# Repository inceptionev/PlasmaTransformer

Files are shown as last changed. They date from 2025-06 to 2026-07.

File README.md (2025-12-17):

# Plasma Transformer

<p align="center">
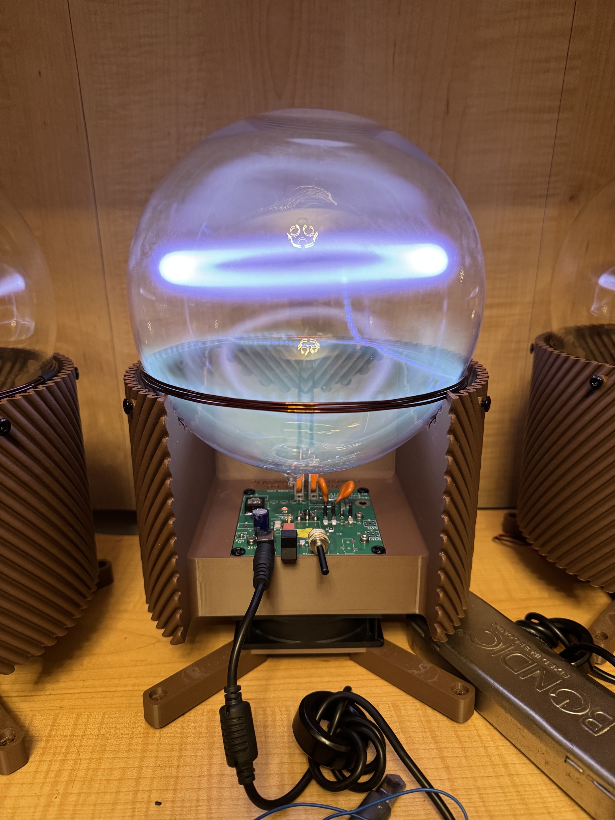
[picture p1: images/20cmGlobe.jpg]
  
</p>

## An open-source plasma toroid project by inceptionev (Dr. Bunga)

This project mainly focuses on creating a driver and 3D-printed support structure that allows for safe continuous operation of a plasma toroid.  The objectives are stable operation of a levitating halo of plasma at maximum height above the coil and protection against touching energized components, while providing airflow to keep both the electronics and the globe cool.  The globes are filled with a low-pressure of xenon gas.

### Key Features of this project:
- Plasma Driver PCB with experimentation-friendly features:
  - Wide input power range from 12-60V for easy power control.  Onboard 12V supply for stable fan and gate drive.
  - High-voltage auto-igniter strikes the plasma whenever plasma is not present, but also does not load the driver when plasma is live.  This helps prevent damage from runaway unloaded oscillation.  Designed in collaboration with @ltwin0.
  - Oscillation detector illuminates to show when the driver is in oscillation, whether or not plasma is present.  Based on a design from Sky-guided.
  - Socketed coil and tank capacitor connectors for easy tuning.
  - Dedicated on-board oscilloscope probes on the MOSFET gate and drain nets for Class-E tuning.  Connect an SMA cable directly from the board to a terminator and the oscilloscope.
  - Selectable Gate-Source cap via jumper headers to tune AC gate drive strenth.
  - Separate power switch and DC Gate Bias control.  Turn it off and on without changing the DC gate bias level.
- 3D printed cooling shroud:
  - Provides directed airflow for cooling both the electronics and the globe for continuous use.
  - Supports the fan, board, coil, and globe with ideal spacing for achieving a levitating plasma halo.
  - Provides attachments for rubber bands to hold the globe in place for environments where the device may be in motion, or to attach a shade to make the plasma more visible in outdoor installations.
  - Includes a cover and coil ring that keeps curious fingers away from the hazardous high-voltage parts. (But caution is always advised around high voltage and RF)
- 3D-printed assembly aids:
  - Coil forms for ease of making the plasma coil.

Special thanks to:  
Sky-guided, whose inductive oscillation indicator design is used in this project.  
@ltwin8, whose RF node parasitic auto-igniter design is used in this project and was detailed in https://github.com/inceptionev/PlasmaTransformer/issues/1  

Native design files and manufacturing files in gerber and stl format are provided for the 20cm and 13cm globe sizes.

<p align="center">
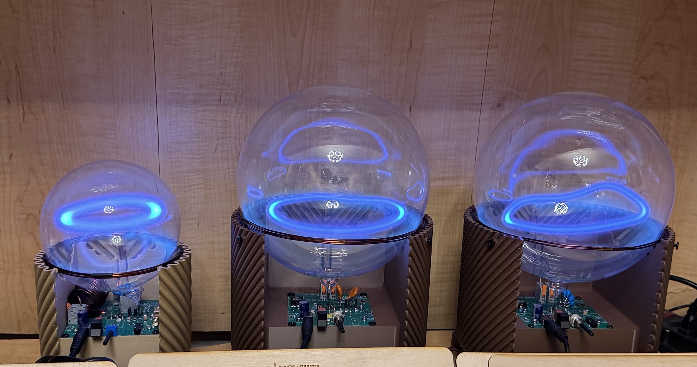
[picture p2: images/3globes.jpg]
  
</p>

KiCAD PCB files are found in the /Plasma Transformer PCB folder.  If you want to edit the design, the files are in the folder.  If you just want to make the boards, you need:
- Plasma Transformer PCB/manufacturing/[the zip file with the latest rev]
- Plasma Transformer PCB/bom/[the bom file matching that rev]

Rev 5 PCB specific note:
The holes for the capacitor sockets are too large, so instead of being press-fit, they will need to be soldered in.  I recommend using a piece of paper tape to hold them in place on the top side, then soldering them on the bottom side.  Or you can skip the sockets and solder in the capacitors directly.

3d print design files and a dxf for the heatsink hole pattern are found in the 3D Print and CNC folder.  The heatsink holes are all M3 drill/tap.

If you are doing turnkey PCBA assembly, you probably want to DNP the fan (M1), heatsink (HS1), MOSFET (Q1), and tank capacitors (C1, C16-20) from the BOM in the Turnkey Assembly ZIP package, as you will assemble these later.

<p align="center">
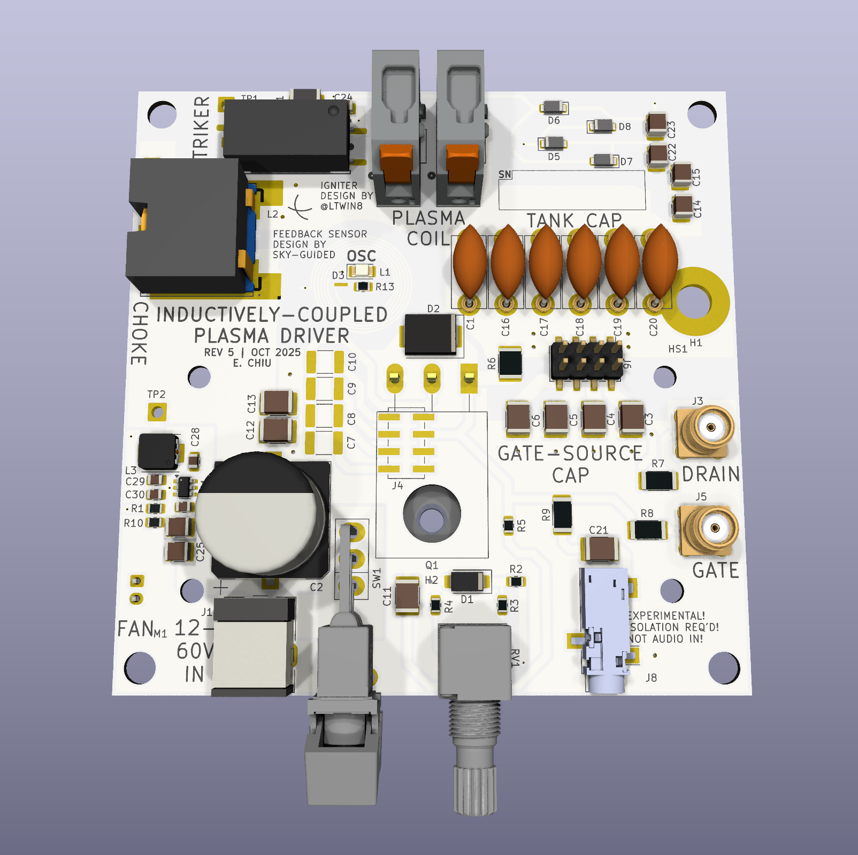
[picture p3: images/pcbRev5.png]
  
</p>

If you just want to print the files, look here:
- /3D Print and CNC/20cm Globe STL 3D Print Set
- /3D Print and CNC/13cm Globe STL 3D Print Set

## Additional Materials Needed:
- 12 AWG magnet wire (2mm dia)
- 12mm or 1/2" polyimide (kapton) tape
- 4x M4*30mm self tapping screws
- 4x M4*8mm self tapping screws
- 4x M3 6x6mm Male/Female threaded standoff
- 4x M3 6mm screws to mount PCB to heatsink
- M3 washers and lockwashers
- JST XHP-2 connector and contacts for fan
- The appropriate capacitor values from the list below
- Thermal pad for TO-247 MOSFET (example: SPK4-0.006-00-104)
- M3*20mm screw, washer, and lockwasher for mounting MOSFET
- 4mm OD x 2.5mm ID PTFE tube (commonly sold as Bowden tube for 1.75mm filament 3D printers)

## Assembly instructions:
- I recommend 3D-printing the coil forms and the spacer ring first, then the cooling shroud, cover, and foot.  You may also want to print a smaller coil form for pre-winding in the first batch, see coil instructions below.
- The main cooling shroud may take 20+ hrs to print, so you can build the heatsink, coil and PCB while it is printing.
- Prepare the heatsink
  - Drill and tap the holes in the heatsink.  They are all M3.  A DXF is provided if you wnat to use a CNC.
  - Mount the MOSFET into the heatsink with thermal pad LOOSELY (do not tighten yet)
  - Bend the MOSFET pins up 90 degrees
  - Install the standoffs into the heatsink
- Assemble the PCB per the BOM EXCEPT for the MOSFET.  That component will be soldered last.
- Mount the PCB to the heatsink with 4x M3x6mm screws, washers, and lockwashers, threading the MOSFET pins through the holes in the board.  Make sure the MOSFET is loose so it can move into alighment with the board.
- Tighten the screws mounting the PCB to the heatsink first.
- Then tighten the mounting screw of the MOSFET to the heatsink.
- Solder the MOSFET in.
- Add connector to the fan.  Pin 1 is positive.
- Make the coil
  - Print out the coil form in the folder for the globe size you are using.
  - Push a length of 12AWG magnet wire in a length of insulating PTFE tube.  It helps if the tube and the wire are both straight.  Taping them to the edge of a table will accomplish this.
    - For the 13cm globe, push 171.6cm of wire into 151.6cm of PTFE tube.  Leave 10cm of wire sticking out at both ends.
	- For the 20cm globe, push 203cm of wire into 175cm of of PTFE tube.  Leave 14cm of wire sticking out at both ends.
  - First wrap the wire and insulator around an object slightly smaller than the coil form.  This will make wrapping on the coil form easier.  You can use the 13cm coil form as the pre-wind form for the 20cm coil. An stl file for an 80mm coil form is also provided to act as the pre-wind for the 13cm coil.
  - Wrap the slightly-smaller coil of wire and insulator onto the coil form.  Start at the lip, and work up from there in a clockwise direction with the lip facing away from you.  This ensures that the bottom coil connects to the RF Node (the right block on the PCB).  This is the higher voltage terminal, and having it on the bottom coil helps with levitation of the plasma.
    - 13cm Globe: you should get 4 coils, minus the 9mm gap where the ends meet.
	- 20cm Globe: you should get 3 coils, minus the 9mm gap where the ends meet.
  - Use the slots in the coil form to tape up the coil so it holds its shape.  Polyimide (Kapton) tape is recommended.
  - Remove the coil from the form and wrap the coil again where the tail meets the coil
  - Open the coil terminal latches on the PCB and fit the coil into the assembly with the PCB, making bends to allow for the envelope of the globe.  Make an 'S' curve at the bottom of the coil wires where they exit the PCB blocks, to allow for adjusting the height.
  - Trim the coil tails if necessary.
  - Burn about 12mm of insulation off the end of the coil tails and clean it up with sandpaper until you can see the shiny copper underneath.  A lighter works well for this.
  - Install the coil spacer ring into the top of the coil, opposite of the direction where the wire tails go.
- Mount the foot and the fan to the bottom with the M4*30mm screws, threading the fan wires through the notch in the bottom.  
- Connect the fan to the PCB.  On the 20mm cooling shroud, a slot is provided in the wall next to the PCB to hold the fan connector temporarily for easy connecting and disconnecting.
- Mount the PCB to the cooling shroud with the M4*8mm screws
- Latch the coil into the PCB.
- Screw in 5x M4x8mm screws into the bosses around the circumference of the cooling shroud. This can be used for shrouds or rubber bands to secure the globe.
- Optionally install the cover into the cooling shroud.

## Known successful values from experimentation:

Supply Voltage:
- 20cm Globe: 24V
- 13cm Globe: 19V

Gate-Drain Cap:
- 20cm Globe: none
- 13cm Globe: none

Resonant Cap:
- 20cm Globe: 3x 24pF 564RC0GAJ602EJ240J
- 13cm Globe: 3x 24pF 564RC0GAJ602EJ240J

Gate-Source Cap:
- 20cm Globe: 2.7nF + 3.6nF + 1.8nF + 1.8nF
- 13cm Globe: 2.7nF

Measured Air Core Inductance of Globe Coils (no globe or plasma present):
- 13cm Globe, 4 turns 122mm x 16mm long: 3.3uH
- 20cm Globe, 3 turns 187mm dia x 12mm long: 3.6uH

## Tips and Tricks for Experimenting with Plasma Toroids:
- The goal of feedback tuning is to minimize the source-drain voltage across the MOSFET during the points of switching, otherwise it will get hot quickly.
- Also be mindful of the voltage rating on the cap between the plasma globe coil and the gate.  This cap will see 1000V+ when the coil is unloaded (when there is no plasma).
- Also be careful of anything in that node.  That means anything between the gate-coil capacitor and the coil, including the bottom turns of the coil.  This is the HF node, aka RF node, where the highest amplitude of voltage oscillation is seen.  It will burn you if you touch it, sometimes even touching insulated portions.  The burn is nearly painless at first, and then painful later.
- The MOSFET and the coil-gate cap are the two most common components to break in this circuit.
- Haloplasma is a good source for the xenon-filled plasma globes.

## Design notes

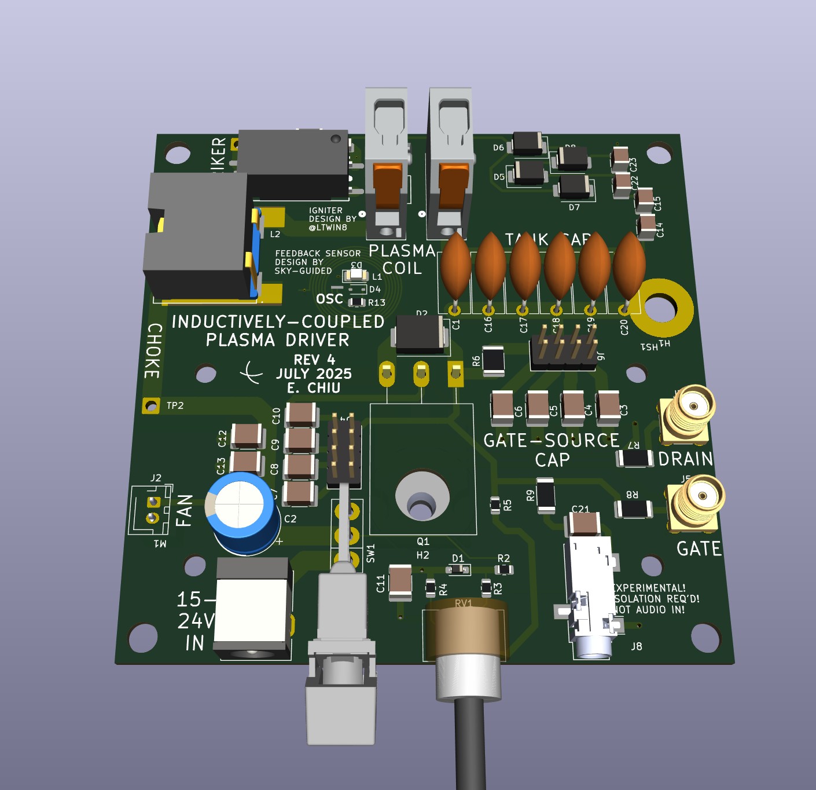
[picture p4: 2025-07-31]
images/pcbRev4.jpg

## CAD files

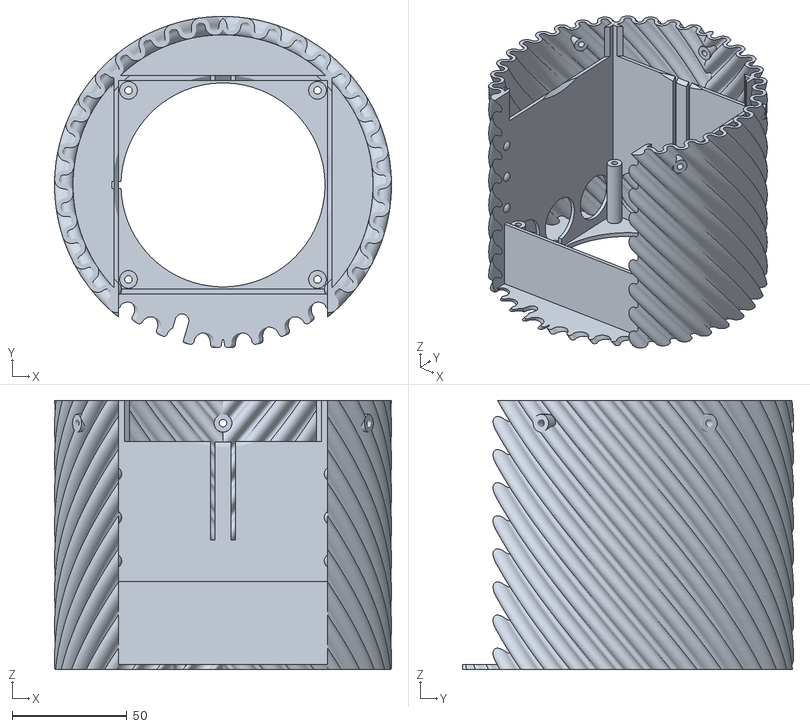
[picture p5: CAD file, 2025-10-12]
3D Print and CNC/13cm Globe STL 3D Print Set/Corrugated-FanShroud-13cm-4coil-MainShroud.stl
147.1 x 144.5 x 117.6

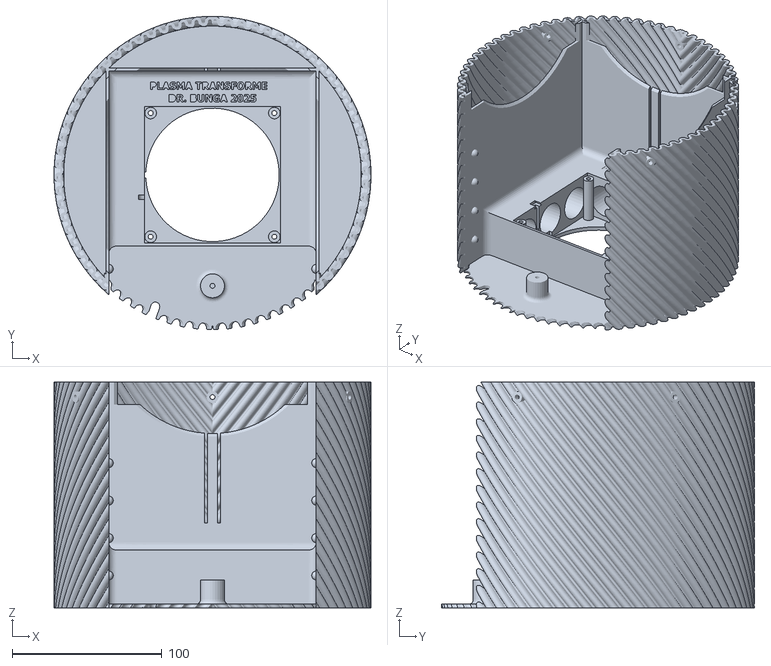
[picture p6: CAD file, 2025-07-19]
3D Print and CNC/20cm Globe STL 3D Print Set/Corrugated-FanShroud-20cm-MainShroud.stl
211.5 x 209.0 x 150.6

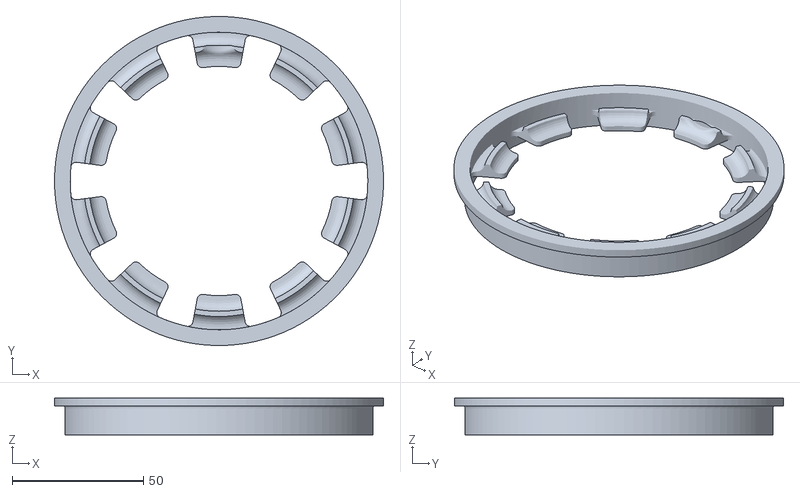
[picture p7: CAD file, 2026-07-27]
3D Print and CNC/13cm-Spacer-10cmDonutEnvelope-5mm.stl
125.4 x 125.4 x 14.0

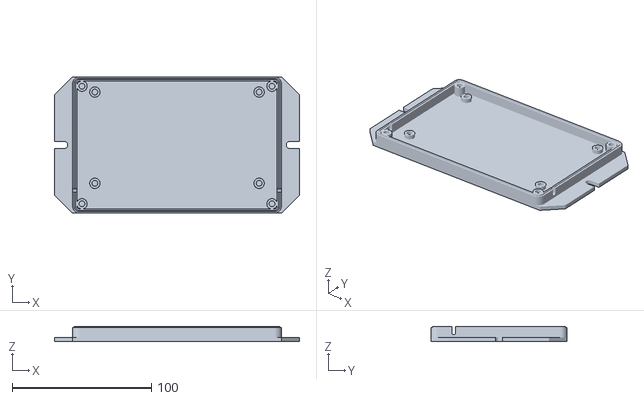
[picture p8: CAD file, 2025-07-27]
3D Print and CNC/DC-DC Power Supply 3d Print Set/DrokSupplyCase-Bottom.stl
176.0 x 98.0 x 11.0

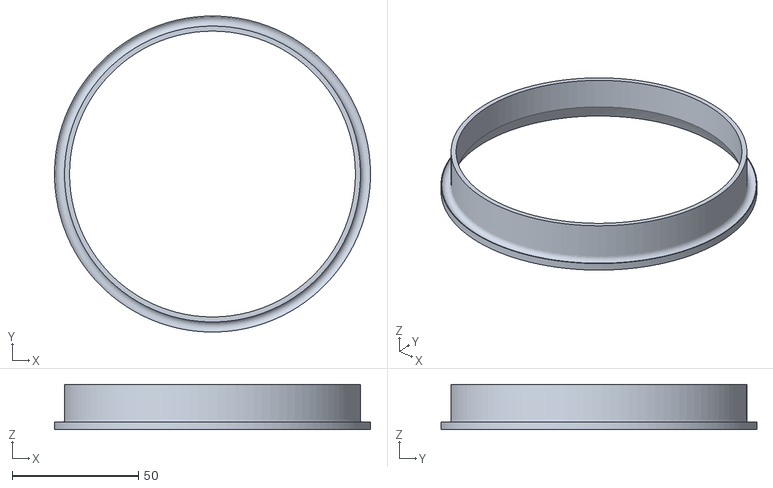
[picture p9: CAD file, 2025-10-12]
3D Print and CNC/13cm Globe STL 3D Print Set/Corrugated-FanShroud-13cm-4coil-Spacer.stl
125.4 x 125.4 x 18.0

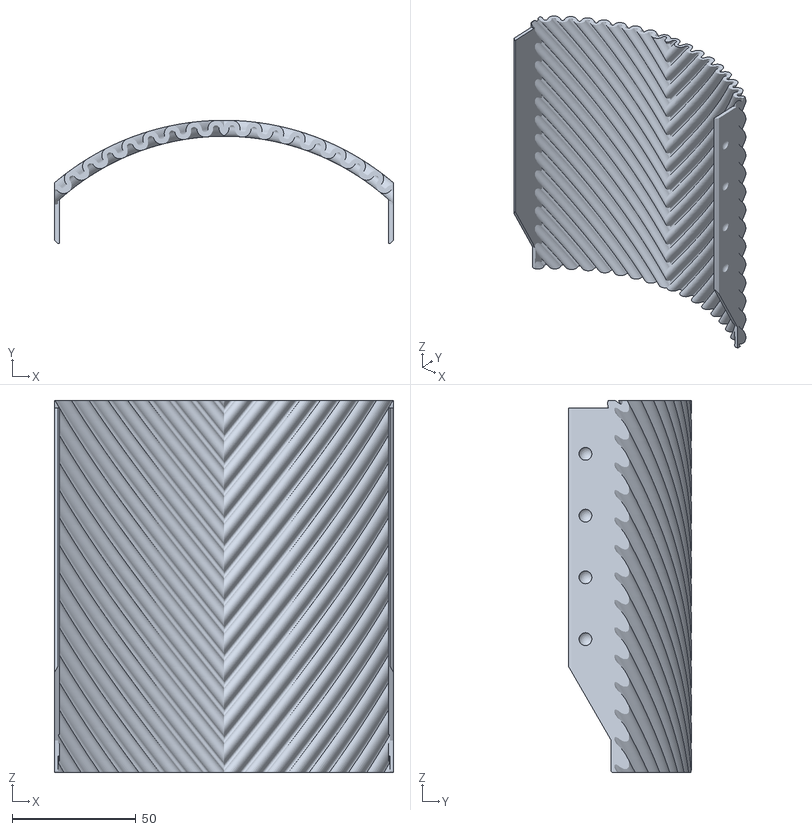
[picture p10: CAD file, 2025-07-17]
3D Print and CNC/20cm Globe STL 3D Print Set/Corrugated-FanShroud-20cm-Cover.stl
137.3 x 50.0 x 150.6

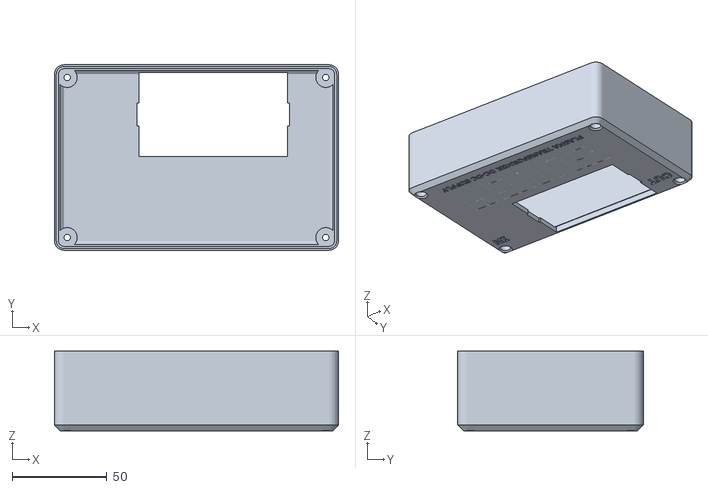
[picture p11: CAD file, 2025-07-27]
3D Print and CNC/DC-DC Power Supply 3d Print Set/DrokSupplyCase-Top.stl
150.0 x 98.0 x 42.0

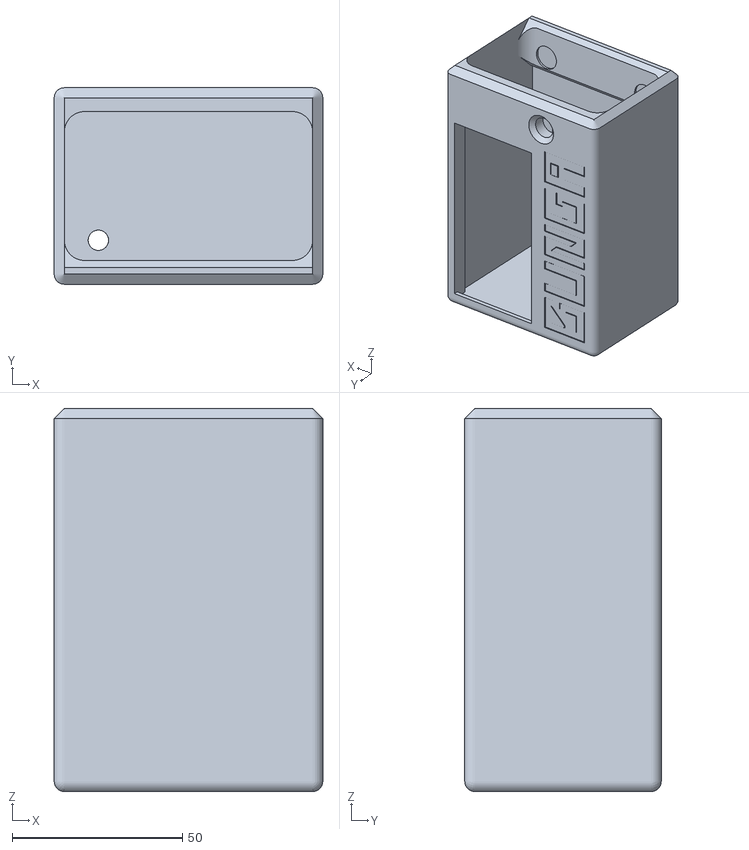
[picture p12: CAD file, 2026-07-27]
3D Print and CNC/PowerSupplyRegulator-OnePiece.stl
79.0 x 57.8 x 112.6

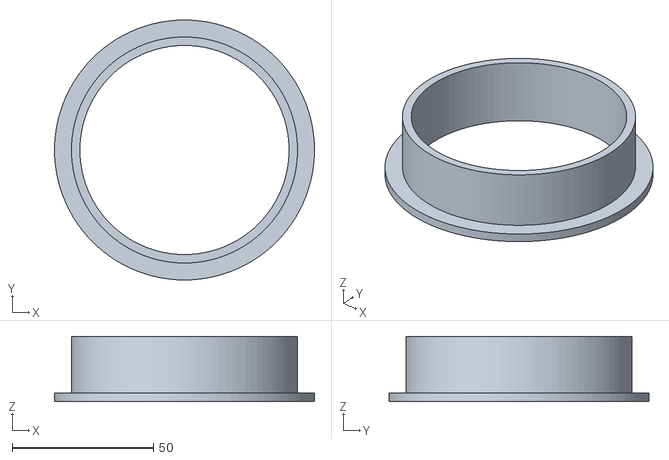
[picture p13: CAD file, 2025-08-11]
3D Print and CNC/13cm Globe STL 3D Print Set/80mm-CoilForm-for-pre-winding.stl
92.0 x 92.0 x 23.0

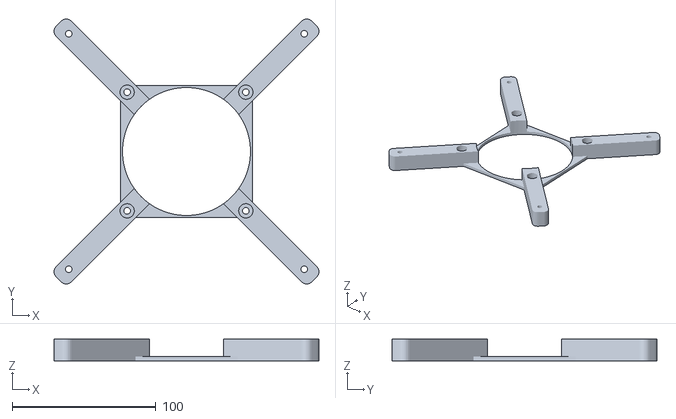
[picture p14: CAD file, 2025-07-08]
3D Print and CNC/20cm Globe STL 3D Print Set/Corrugated-FanShroud-20cm-Foot.stl
184.2 x 184.2 x 15.0

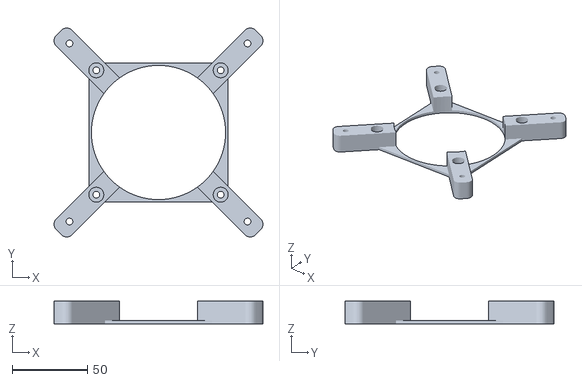
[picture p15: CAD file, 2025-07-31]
3D Print and CNC/13cm Globe STL 3D Print Set/Corrugated-FanShroud-13cm-Foot.stl
138.6 x 138.6 x 15.0

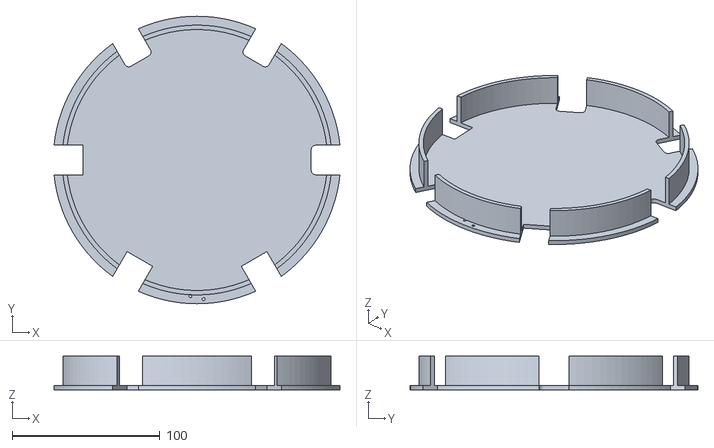
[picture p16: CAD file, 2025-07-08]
3D Print and CNC/20cm Globe STL 3D Print Set/187mm-CoilForm-4mmCoil.stl
193.8 x 194.8 x 23.0

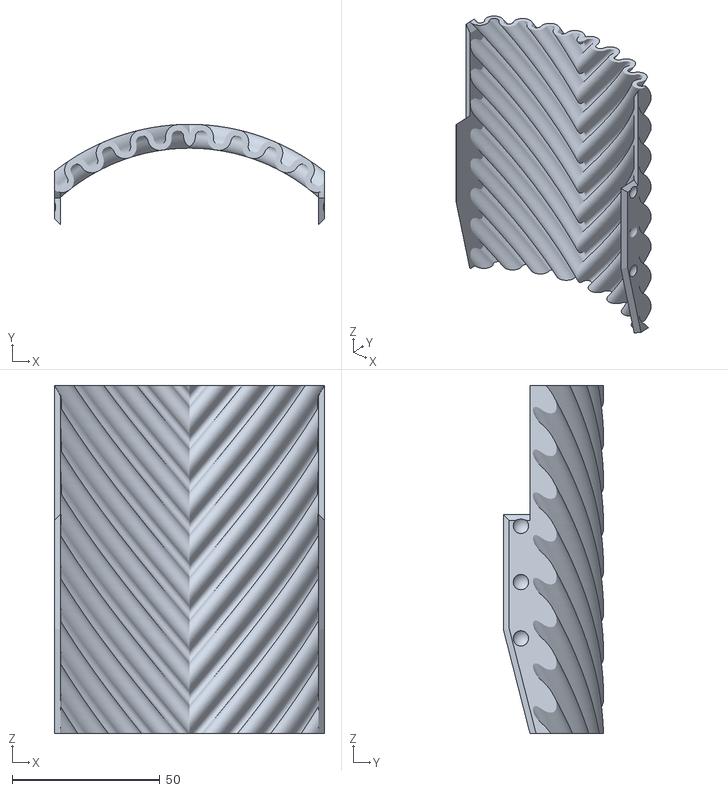
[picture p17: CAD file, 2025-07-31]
3D Print and CNC/13cm Globe STL 3D Print Set/Corrugated-FanShroud-13cm-Cover.stl
91.3 x 33.9 x 117.6

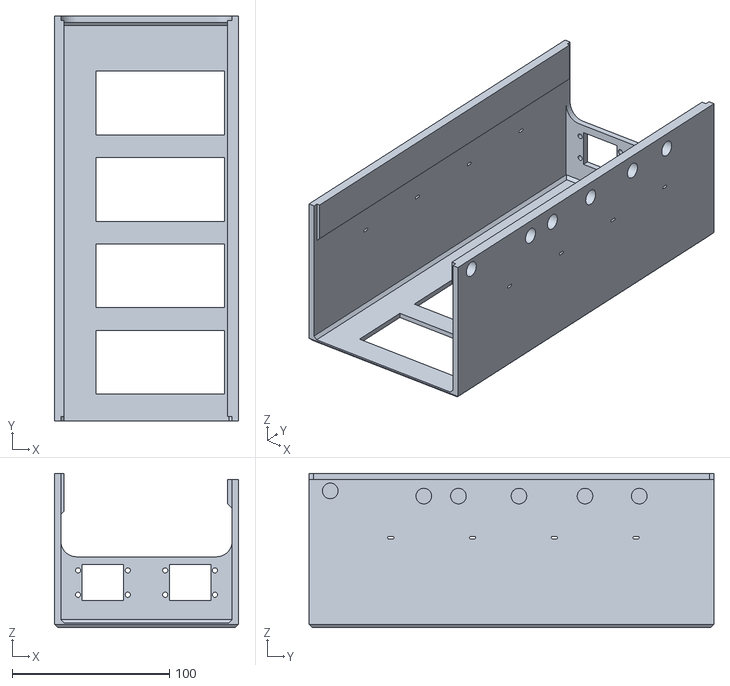
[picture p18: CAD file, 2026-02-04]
3D Print and CNC/QuadSupply.stl
117.0 x 257.5 x 98.0

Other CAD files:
3D Print and CNC/13cm-Spacer-10cmDonutEnvelope.stl
3D Print and CNC/PowerSupplyCase-585W-Base.stl
3D Print and CNC/PowerSupplyCase-585W-Top.stl
3D Print and CNC/ConformalCoatingJig.stl
3D Print and CNC/122mm-CoilForm-6mmCoil.ipt
3D Print and CNC/122mm-CoilForm.ipt
3D Print and CNC/13cm-Spacer-10cmDonutEnvelope.ipt
3D Print and CNC/15cmPasteMaskTemplate.ipt
3D Print and CNC/15cmPasteMaskTemplate.stl
3D Print and CNC/187mm-CoilForm.ipt
3D Print and CNC/80mm-CoilForm.ipt
3D Print and CNC/ConformalCoatingJig.ipt
3D Print and CNC/Corrugated-FanShroud-13cm.ipt
3D Print and CNC/Corrugated-FanShroud-20cm.ipt
3D Print and CNC/DrokSupplyCase.ipt
3D Print and CNC/FanShroud-20cm.ipt
3D Print and CNC/FanShroud-20cm.stl
3D Print and CNC/FanShroud-Foot.stl
3D Print and CNC/FanShroud.ipt
3D Print and CNC/FanShroud.stl
3D Print and CNC/PowerSupplyCase-585W.ipt
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

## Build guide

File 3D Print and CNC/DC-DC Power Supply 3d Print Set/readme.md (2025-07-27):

This is a screw mountable case for an adjustable DC-DC stepdown power supply that makes it easy to power the plasma toroid from various power sources.  The external voltage control makes changing the power level more convenient than reaching in to adjust the pot on the PCB inside the assembly.  You can set the bias pot on the PCB to a level that reliably oscillates at your minimum voltage driving level, then control the power level externally by changing the input voltage via this adjustable supply.

This DC-DC converter goes by different names, and comes from labels like Drok and Go DIY, but it usually is called something like 6-75V CNC adjustable supply.  This is one such example: https://www.amazon.com/dp/B0D9LB3YQN

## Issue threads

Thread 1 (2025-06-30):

Trigger circuit, passively parasite power mode tapping RF Node

ltwin8, 2025-06-30:
As discussed in the opensource plasma toroid community. Just a quick sketch of schematic.

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

A short description:

Use 300V GDT

C6/C7 should be dimensioned in such way that they do carry around 1% of the expected RF Current or be 100 times its impedance at resonant frequency to pose a minimal effect during operation (static and igniting)

C6 should drop the voltage required by the GDT to fire when UNLOADED by plasma (i.e. no toroid ignited)

Diodes HAVE TO BE able to handle the task, low junction capacitance, low recovery time, thats the tricky components, if dimensioned correctly 400V or more is enough.

C5 should be 500V X7R or even better FILM, low ESR.

the trigger transformer is not as strickt, i would use BO-02 for its super small size.

The circuit, especially the high current part HAS TO BE routed very compact to midigate parasitic inductances. try to place as close to toroid as possible. use very thin masgnet wire for trigger electrode to keep it effective (lowest possible capacitance thus higher dV/dt), do not use thick isolation but space it enough physically

inceptionev, 2025-07-27:
Implemented in Rev 3B, to be rolled into Rev 4 eventually.  Tested and works well.

Closed 2025-07-27.

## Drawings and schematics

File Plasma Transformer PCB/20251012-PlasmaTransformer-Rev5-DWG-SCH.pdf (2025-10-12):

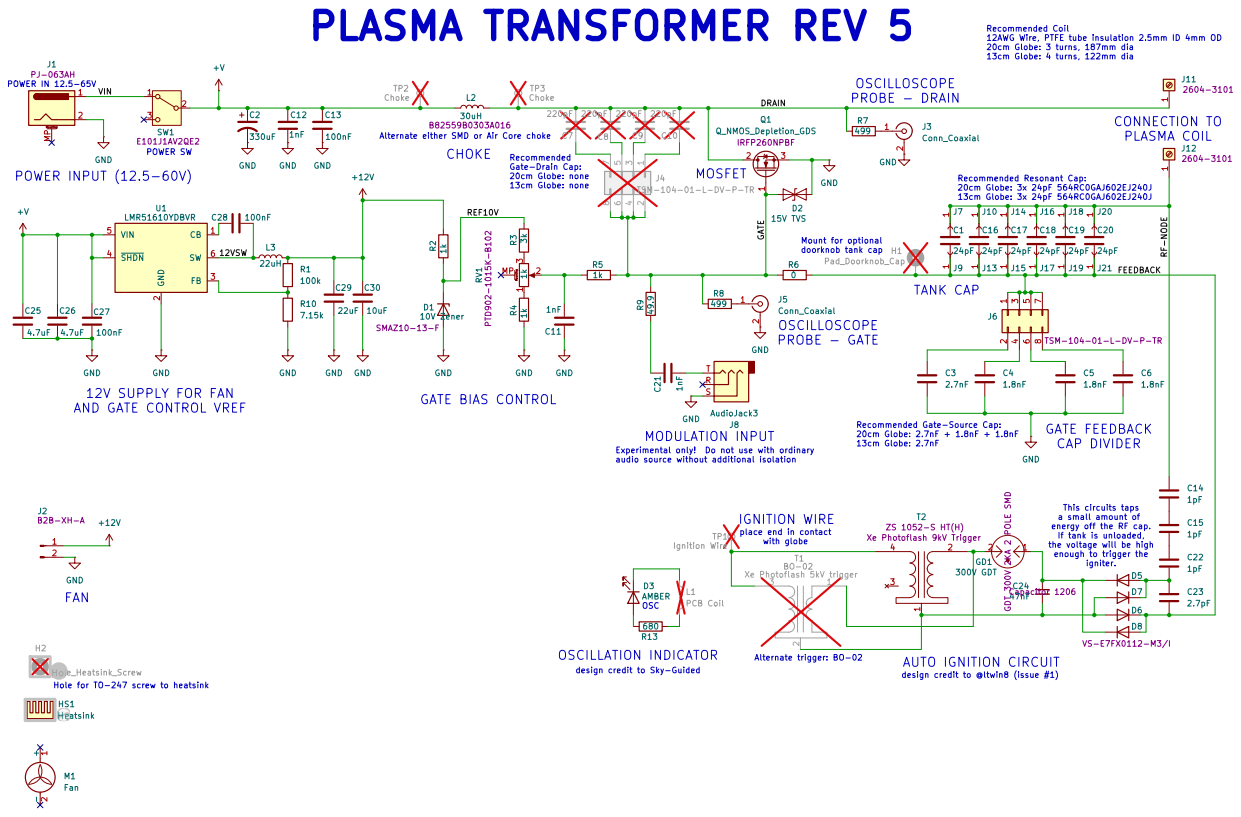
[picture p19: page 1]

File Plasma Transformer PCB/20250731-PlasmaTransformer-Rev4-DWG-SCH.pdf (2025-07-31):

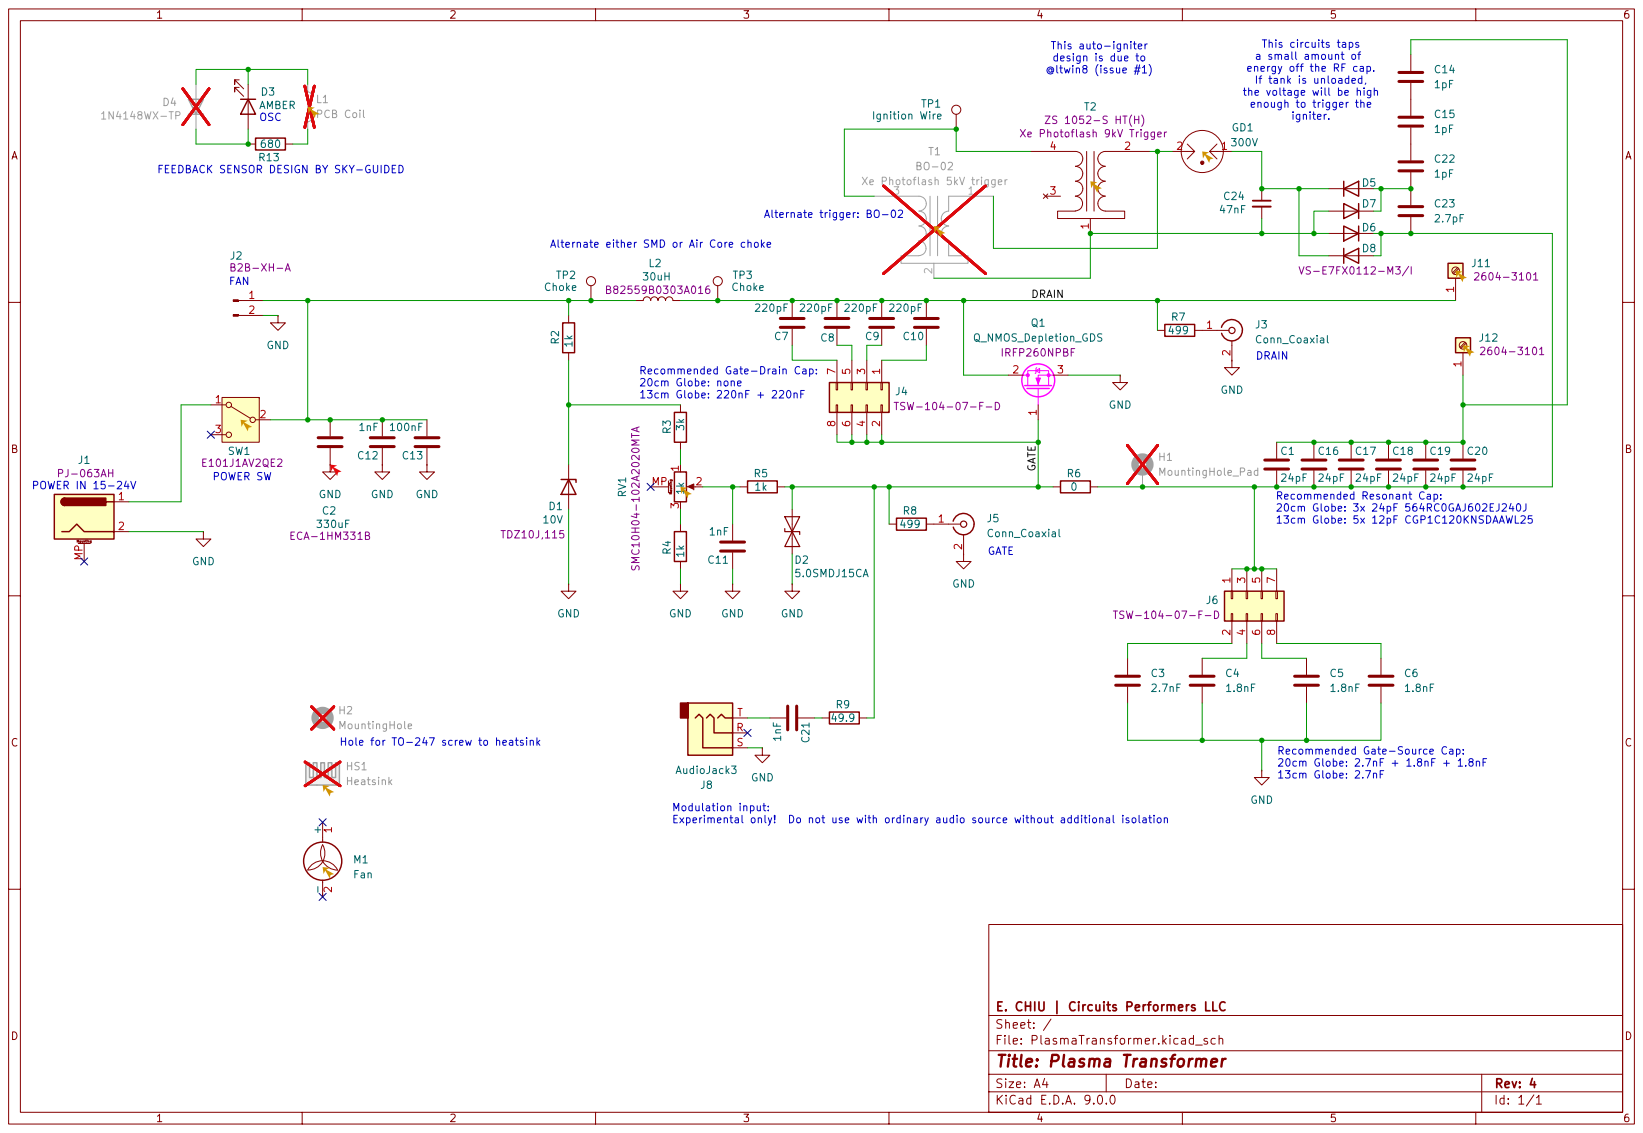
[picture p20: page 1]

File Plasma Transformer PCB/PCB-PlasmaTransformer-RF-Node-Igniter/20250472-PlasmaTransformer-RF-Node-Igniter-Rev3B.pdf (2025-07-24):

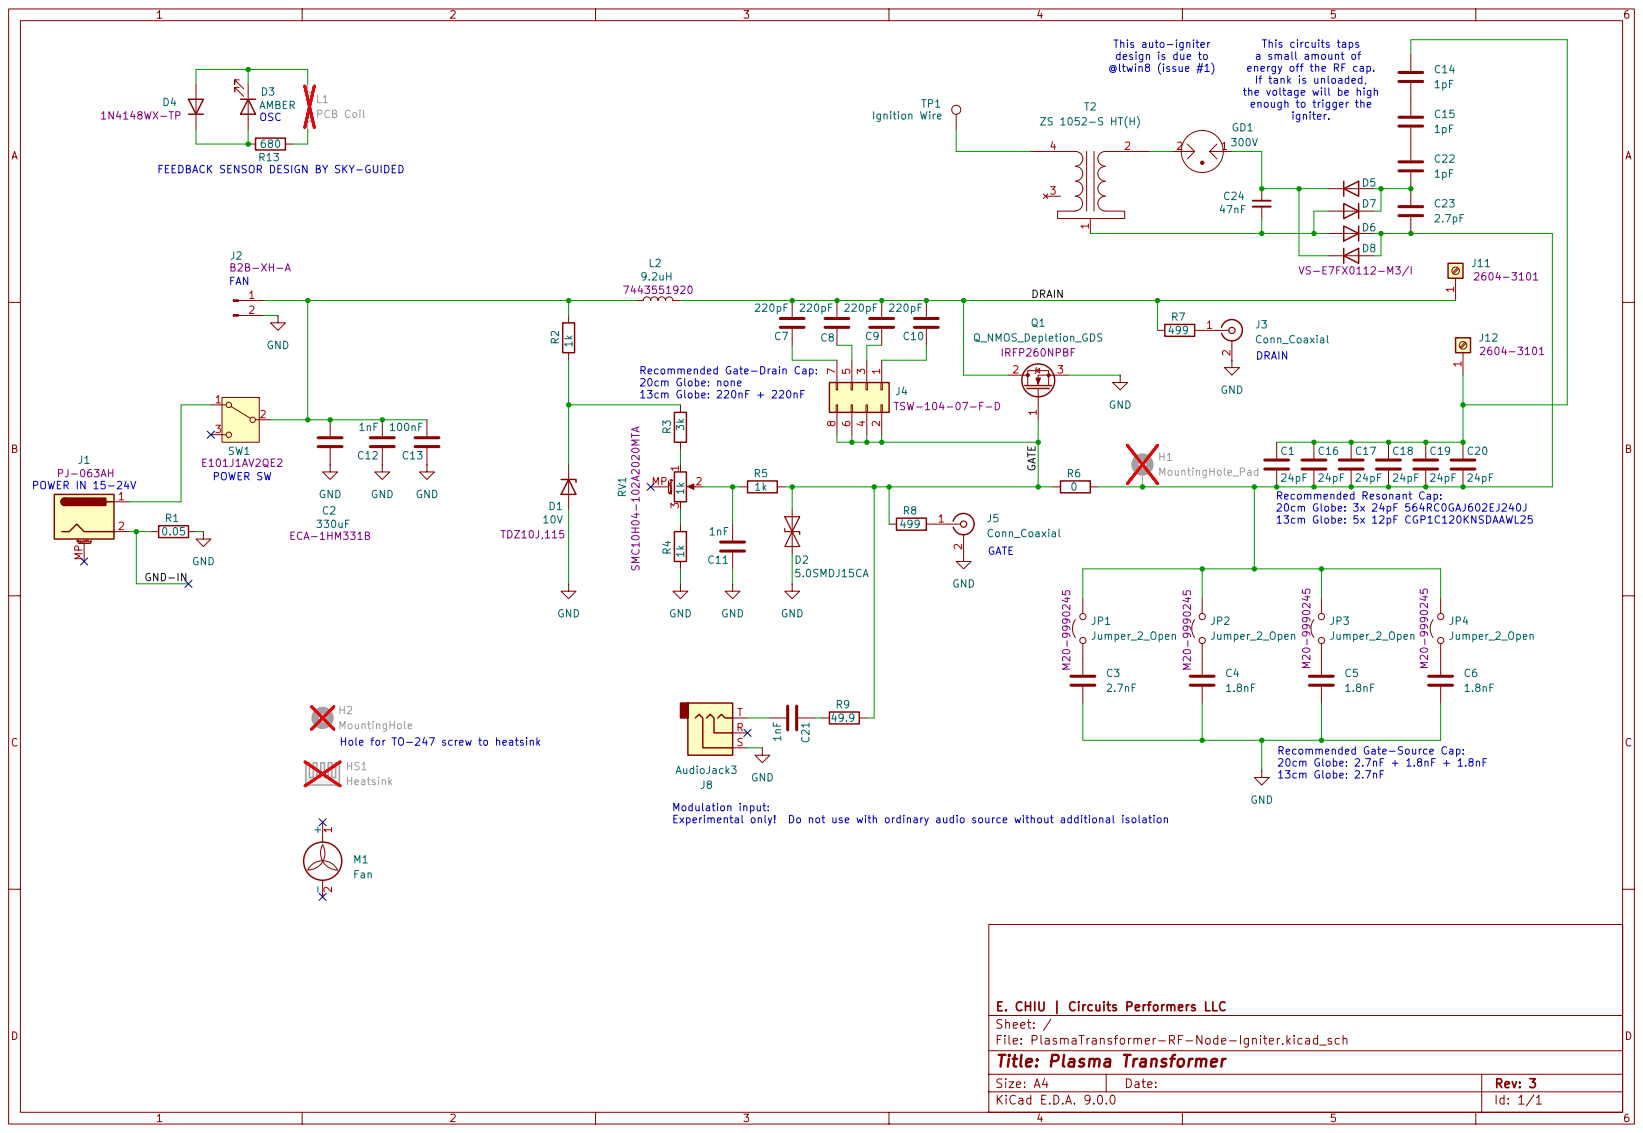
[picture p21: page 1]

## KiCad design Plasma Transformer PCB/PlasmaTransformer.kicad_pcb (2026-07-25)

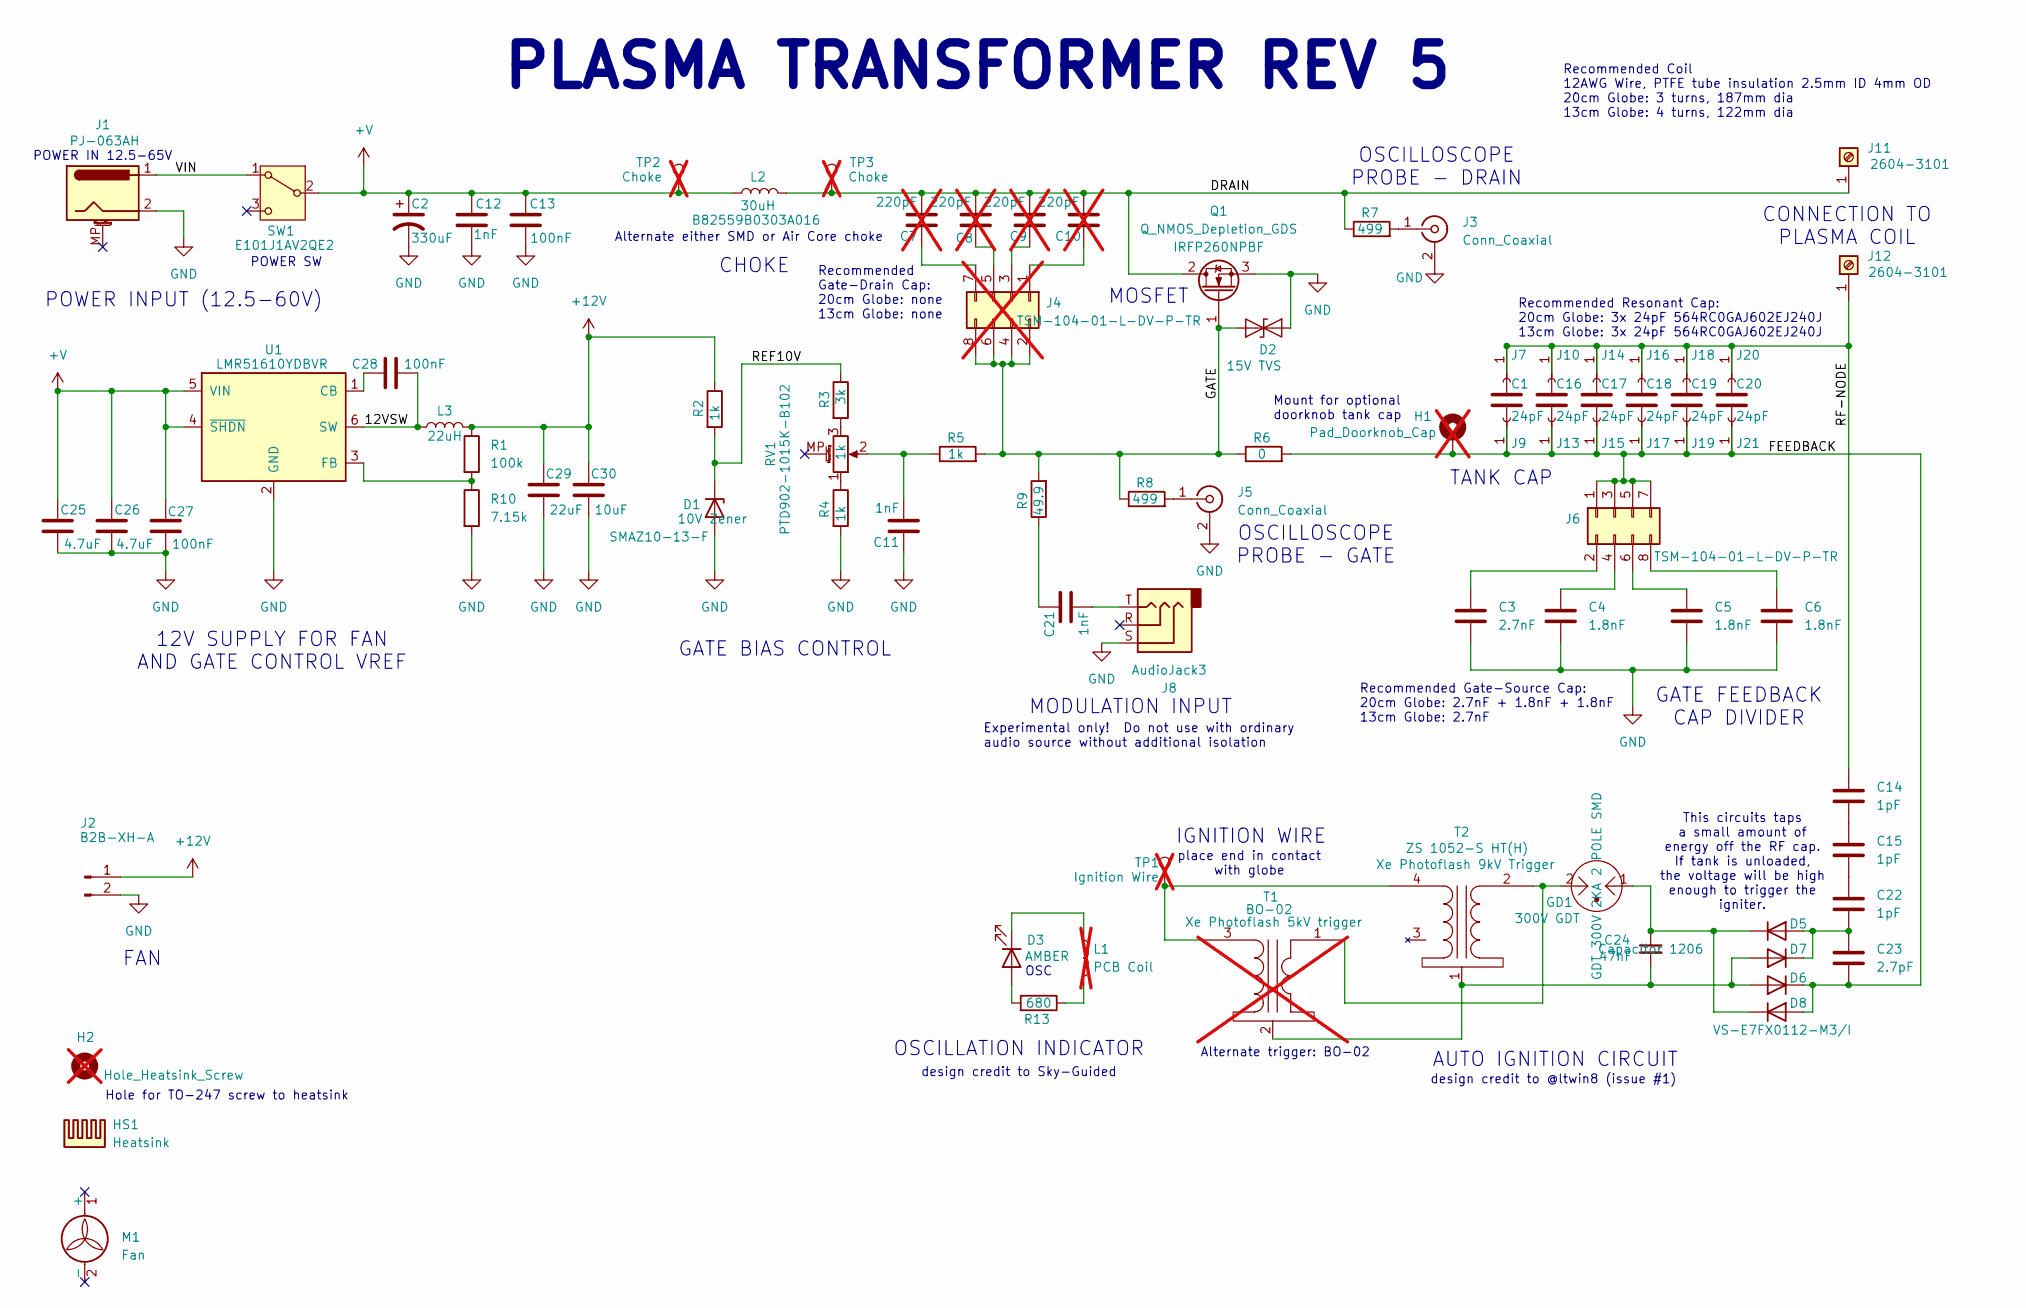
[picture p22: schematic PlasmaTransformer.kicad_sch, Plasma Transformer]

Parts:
C1, C16, C17, C18, C19, C20: 24pF; C_Disc_D11.0mm_W5.0mm_P10.00mm; Voltage 6000V; MPN 564RC0GAJ602EJ240J
C2: 330uF; CP_Elec_16x17.5_FK_Series; Voltage 80V; MPN EEV-FK1K331M
C3: 2.7nF; C_1812_4532Metric; Voltage 2000V; MPN 1812GC272KAT1A
C4, C5, C6: 1.8nF; C_1812_4532Metric; Voltage 500V; MPN C1812C182JCGACTU
C7, C8, C9, C10: 220pF; C_1812_4532Metric; Voltage 1000V; MPN CC1812JKNPOCBN221; not fitted
C11, C12, C21: 1nF; C_1812_4532Metric; Voltage 2000V; MPN VJ1812A102JXFTW1HV
C13: 100nF; C_1812_4532Metric; Voltage 1000V; MPN GRM43DR7LW104KW01K
C14, C15, C22: 1pF; C_1210_3225Metric; Voltage 2000V; MPN 111122K01P00BQTAF9LM
C23: 2.7pF; C_1210_3225Metric; Voltage 2000V; MPN 111122K02P70HQTAF9LM
C24: 47nF; C_1206_3216Metric; Voltage 500V; MPN C1206C473KCRACTU
C25, C26: 4.7uF; C_1210_3225Metric; Voltage 100V; MPN CL32B475KCVZW6E
C27, C28: 100nF; C_0805_2012Metric; Voltage 100V; MPN C2012X7R2A104K125AA
C29: 22uF; C_0805_2012Metric; Voltage 25V; MPN CL21A226MAYNNNE
C30: 10uF; C_0805_2012Metric; Voltage 25V; MPN CL21A106KAYNNNE
D1: 10V Zener; D_SMA; MPN SMAZ10-13-F
D2: 15V TVS; D_SMC; MPN 5.0SMDJ15CA
D3: AMBER; LED_1206_3216Metric; MPN 150120AS75000
D5, D6, D7, D8: D; D_SMF; Voltage 1200V; MPN VS-E7FX0112-M3/I
GD1: 300V GDT; L_1812_4532Metric; MPN 2051-30-SM-RPLF
H1: Pad_Doorknob_Cap; MountingHole_5.3mm_M5_Pad; not fitted
H2: Hole_Heatsink_Screw; MountingHole_8.4mm_M8; not fitted
HS1: Heatsink; Heatsink_75x37.5mm_Fischer_SK-594-37.5-AL; MPN SK 594 37,5 AL
J1: Barrel_Jack_MountingPin; BarrelJack_CUI_PJ-063AH_Horizontal; MPN PJ-063AH
J2: Conn_01x02_Pin; JST_XH_B2B-XH-A_1x02_P2.50mm_Vertical; MPN B2B-XH-A
J3, J5: Conn_Coaxial; SMA_Amphenol_901-144_Vertical; MPN RFPC-SMA28-F
J4: Conn_02x04_Odd_Even; PinHeader_2x04_P2.54mm_Vertical_SMD; MPN TSM-104-01-L-DV-P-TR; not fitted
J6: Conn_02x04_Odd_Even; PinHeader_2x04_P2.54mm_Vertical_SMD; MPN TSM-104-01-L-DV-P-TR
J7, J9, J10, J13, J14, J15, J16, J17, J18, J19, J20, J21: Conn_01x01_Socket; H8501-05; MPN H8501-05
J8: AudioJack3; Jack_3.5mm_CUI_SJ-3523-SMT_Horizontal; MPN SJ-3523-SMT-TR
J11, J12: Screw_Terminal_01x01; CONN_2604-3101_WAG; MPN 2604-3101
L1: PCB Coil; FEEDBACK_COIL_B; not fitted
L2: 30uH; B82559B_TDK; MPN B82559B0303A016
L3: 22uH; L_Pana_PCC-KVP_5.5x5mm; MPN ETQ-P3M220KVP
M1: Fan; FAN AXIAL 92X25.4MM; MPN AFB0912VHD-F00
Q1: Q_NMOS_Depletion_GDS; TO-247-3_Horizontal_TabDown; MPN IRFP260NPBF
R1: 100k; R_0805_2012Metric; Tolerance 1%; MPN RC0805FR-07100KL
R2, R4, R5: 1k; R_0805_2012Metric; Tolerance 1%; MPN RC0805FR-071KL
R3: 3k; R_0805_2012Metric; Tolerance 1%; MPN RC0805FR-073KL
R6: 0; R_1812_4532Metric; Tolerance 1%; MPN ERJ-12Y0R00U
R7, R8: 499; R_2010_5025Metric; Tolerance 1%; MPN RC2010FK-07499RL
R9: 49.9; R_2010_5025Metric; Tolerance 1%; MPN RC2010FK-0749R9L
R10: 7.15k; R_0805_2012Metric; Tolerance 1%; MPN RC0805FR-077K15L
R13: 680; R_0805_2012Metric; Tolerance 1%; MPN RC0805FR-07680RL
RV1: 1k; Bourns-Potentiometer-PTD902-2; MPN PTD902-1015K-B102
SW1: SW_SPDT; CKSW-E101J1AV2QE2; MPN E101J1AV2QE2
T1: BO-02; MPN BO-02; not fitted
T2: ZS 1052-S HT(H); MPN ZS 1052-S HT(H)
TP1: Ignition Wire; SolderWire-0.75sqmm_1x01_D1.25mm_OD2.3mm; not fitted
TP2, TP3: Choke; SolderWire-1sqmm_1x01_D1.4mm_OD2.7mm; not fitted
U1: LMR51610YDBVR; SOT-23-6; MPN LMR51610YDBVR

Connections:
+12V: C29.2, C30.2, J2.1, L3.2, R1.1, R2.1
+V: C2.1, C12.2, C13.2, C25.1, C26.1, C27.2, L2.1, SW1.2 (B), TP2.1, U1.4 (~SHDN), U1.5 (VIN)
/12VSW: C28.1, L3.1, U1.6 (SW)
/DRAIN: C7.2, C8.2, C9.2, C10.2, J11.1, L2.2, Q1.2 (D), R7.1, TP3.1
/FEEDBACK: C1.2, C16.2, C17.2, C18.2, C19.2, C20.2, C23.2, D6.1 (K), D8.2 (A), H1.1, J6.1, J6.3, J6.5, J6.7, J9.1, J13.1, J15.1, J17.1, J19.1, J21.1, R6.2
/GATE: D2.1 (A1), J4.2, J4.4, J4.6, J4.8, Q1.1 (G), R5.2, R6.1, R8.1, R9.2
/REF10V: D1.1 (K), R2.2, R3.1
/RF-NODE: C1.1, C14.1, C16.1, C17.1, C18.1, C19.1, C20.1, J7.1, J10.1, J12.1, J14.1, J16.1, J18.1, J20.1
/VIN: J1.1, SW1.1 (A)
GND: C2.2, C3.2, C4.2, C5.2, C6.2, C11.1, C12.1, C13.1, C25.2, C26.2, C27.1, C29.1, C30.1, D1.2 (A), D2.2 (A2), J1.2, J2.2, J3.2 (Ext), J5.2 (Ext), J8.S, Q1.3 (S), R4.2, R10.2, U1.2 (GND)
unnamed: C11.2, R5.1, RV1.2
unnamed: C14.2, C15.1
unnamed: C15.2, C22.1
unnamed: C21.1, R9.1
unnamed: C21.2, J8.T
unnamed: D3.2 (A), R13.2
unnamed: D3.1 (K), L1.1
unnamed: C22.2, C23.1, D5.2 (A), D7.1 (K)
unnamed: C24.1, D5.1 (K), D8.1 (K), GD1.1
unnamed: C24.2, D6.2 (A), D7.2 (A), T1.2 (AB), T2.1 (AB)
unnamed: J3.1 (In), R7.2
unnamed: C10.1, J4.1
unnamed: C9.1, J4.3
unnamed: C8.1, J4.5
unnamed: C7.1, J4.7
unnamed: J5.1 (In), R8.2
unnamed: C3.1, J6.2
unnamed: C4.1, J6.4
unnamed: C5.1, J6.6
unnamed: C6.1, J6.8
unnamed: L1.2, R13.1
unnamed: R3.2, RV1.3
unnamed: R4.1, RV1.1
unnamed: GD1.2, T1.1 (Primary), T2.2 (AA)
unnamed: T1.3 (Secondary), T2.4 (SB), TP1.1
unnamed: C28.2, U1.1 (CB)
unnamed: R1.2, R10.1, U1.3 (FB)

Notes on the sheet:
GATE BIAS CONTROL
Hole for TO-247 screw to heatsink
12V SUPPLY FOR FAN AND GATE CONTROL VREF
IGNITION WIRE
AUTO IGNITION CIRCUIT
design credit to @ltwin8 (issue #1)
This circuits taps a small amount of energy off the RF cap. If tank is unloaded, the voltage will be high enough to trigger the igniter.
POWER INPUT (12.5-60V)
OSCILLOSCOPE PROBE - GATE
OSCILLATION INDICATOR
CHOKE
Recommended Resonant Cap: 20cm Globe: 3x 24pF 564RC0GAJ602EJ240J 13cm Globe: 3x 24pF 564RC0GAJ602EJ240J
Alternate trigger: BO-02
CONNECTION TO PLASMA COIL
Recommended Coil 12AWG Wire, PTFE tube insulation 2.5mm ID 4mm OD 20cm Globe: 3 turns, 187mm dia 13cm Globe: 4 turns, 122mm dia
MODULATION INPUT
POWER IN 12.5-65V
Experimental only! Do not use with ordinary audio source without additional isolation
MOSFET
PLASMA TRANSFORMER REV 5
design credit to Sky-Guided
Recommended Gate-Drain Cap: 20cm Globe: none 13cm Globe: none
GATE FEEDBACK CAP DIVIDER
POWER SW
place end in contact with globe
OSC
Recommended Gate-Source Cap: 20cm Globe: 2.7nF + 1.8nF + 1.8nF 13cm Globe: 2.7nF
Mount for optional doorknob tank cap
Alternate either SMD or Air Core choke
OSCILLOSCOPE PROBE - DRAIN
TANK CAP
FAN

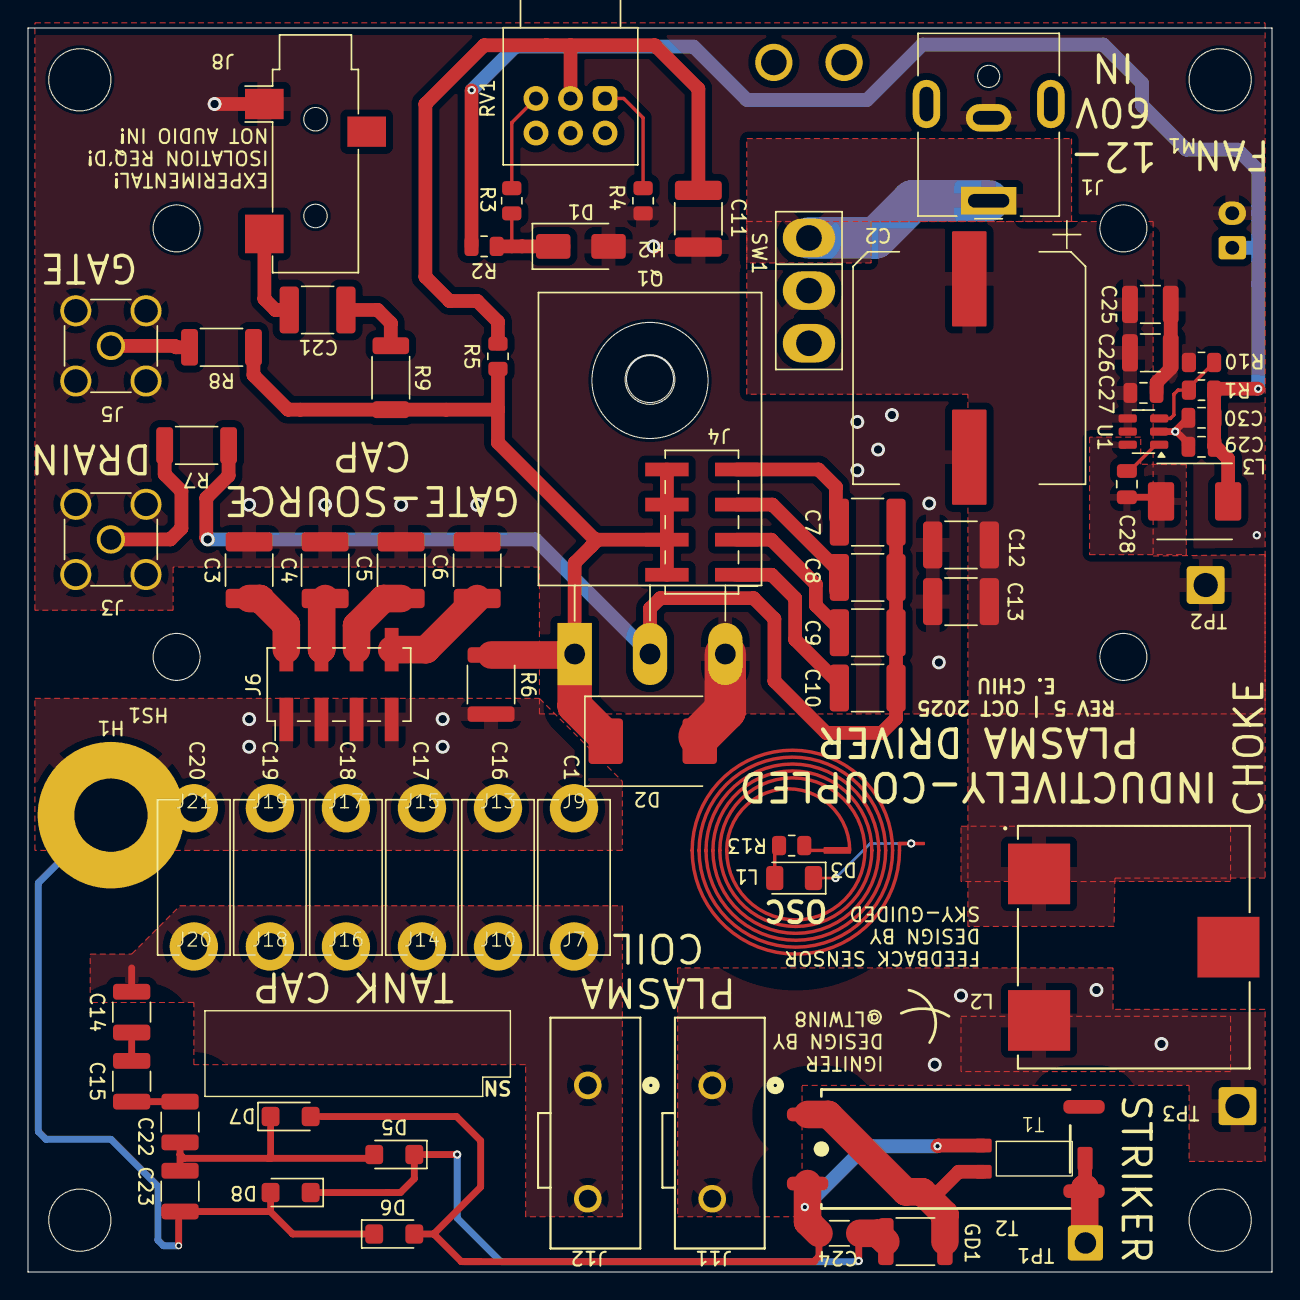
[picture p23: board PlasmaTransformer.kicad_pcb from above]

Board: 2 copper layers, 90.0 x 90.0 mm, 86 parts (1 on the bottom side), 37 nets.

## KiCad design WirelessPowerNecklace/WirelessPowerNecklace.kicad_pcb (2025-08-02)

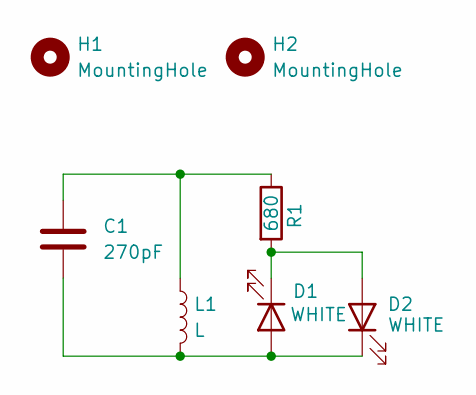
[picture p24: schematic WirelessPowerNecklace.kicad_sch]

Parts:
C1: 270pF; C_1206_3216Metric; MPN CL31C271JIHNNNE
D1, D2: WHITE; LED_1206_3216Metric; MPN LTW-150TK
H1, H2: MountingHole; MountingHole_2.1mm
L1: L; PCB-Coil-ID15mm-6T
R1: 680; R_1206_3216Metric; MPN RC0805FR-07680RL

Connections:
unnamed: C1.1, L1.1, R1.1
unnamed: C1.2, D1.2 (A), D2.1 (K), L1.2
unnamed: D1.1 (K), D2.2 (A), R1.2

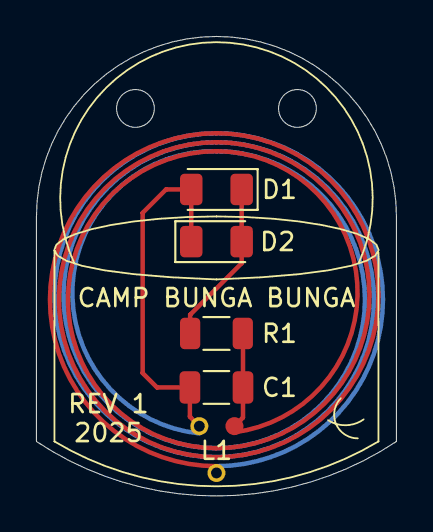
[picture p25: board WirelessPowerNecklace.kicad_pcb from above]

Board: 2 copper layers, 20.0 x 25.5 mm, 7 parts (0 on the bottom side), 3 nets.

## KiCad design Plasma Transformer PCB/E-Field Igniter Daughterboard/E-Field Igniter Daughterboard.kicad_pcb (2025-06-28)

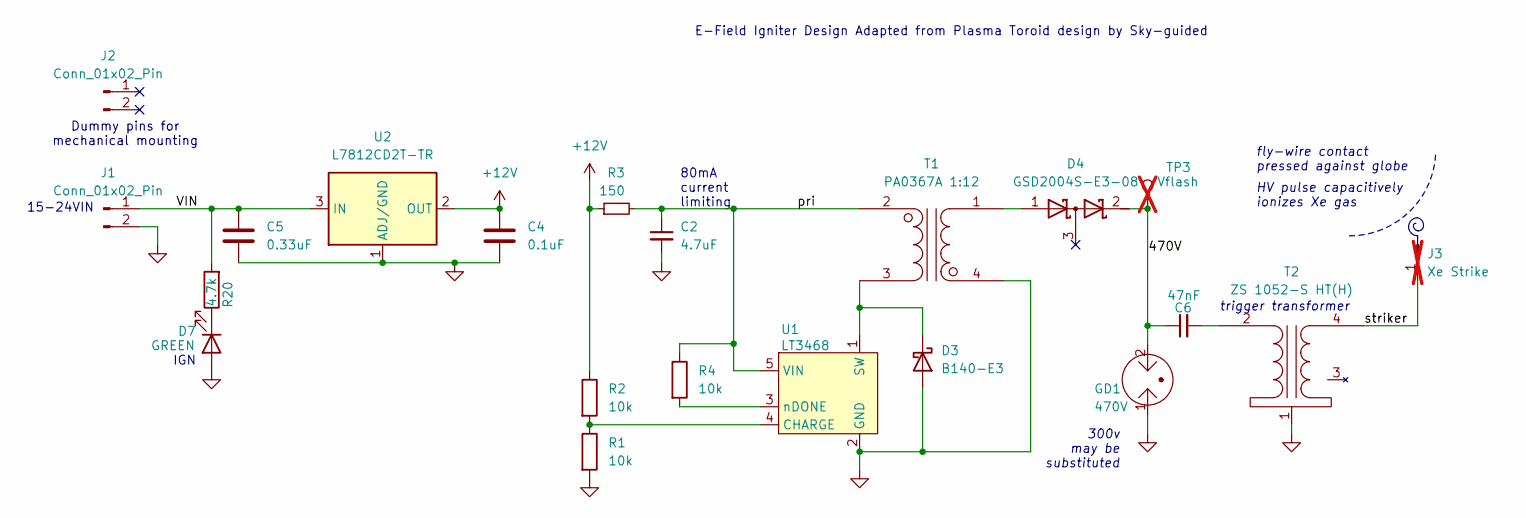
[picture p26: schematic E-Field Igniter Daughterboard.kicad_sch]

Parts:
C2: 4.7uF; C_1206_3216Metric; MPN C3216X7R1E475K160AC
C4: 0.1uF; C_0805_2012Metric; MPN KGM21NR71H104KT
C5: 0.33uF; C_0805_2012Metric; MPN CL21B334KBFNNNE
C6: 47nF; C_1206_3216Metric; MPN C1206C473KCRACTU
D3: B140-E3; D_SMA; MPN B140-E3/61T
D4: GSD2004S-E3-08; SOT-23; MPN GSD2004S-E3-08
D7: GREEN; LED_1206_3216Metric; MPN 150120VS75000
GD1: 470V; L_1812_4532Metric; MPN 2051-30-SM-RPLF
J1, J2: Conn_01x02_Pin; PinHeader_1x02_P1.00mm_Vertical; MPN M20-9990245
J3: Xe Strike; SolderWire-1sqmm_1x01_D1.4mm_OD2.7mm; not fitted
R1, R2, R4: 10k; R_0805_2012Metric; MPN RC0805FR-1310KP
R3: 150; R_0805_2012Metric; MPN RC0805FR-07150RL
R20: 4.7k; R_0805_2012Metric; MPN RC0805FR-134K7L
T1: PA0367A 1:12; PA0367A; MPN PA0367ANLT
T2: ZS 1052-S HT(H); MPN ZS 1052-S HT(H)
TP3: Vflash; TestPoint_THTPad_D2.0mm_Drill1.0mm; not fitted
U1: LT3468; SOT-23-5; MPN LT3468ES5-1#TRMPBF
U2: L7812CD2T-TR; TO-263-2; MPN L7812CD2T-TR

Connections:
+12V: C4.1, R2.1, R3.1, U2.2 (OUT)
/470V: C6.1, D4.2 (K), GD1.2, TP3.1
/VIN: C5.1, J1.1, R20.2, U2.3 (IN)
/pri: C2.1, R3.2, R4.1, T1.2 (AA), U1.5 (VIN)
/striker: J3.1, T2.4 (SB)
GND: C2.2, C4.2, C5.2, D3.2 (A), D7.2 (A), GD1.1, J1.2, R1.2, T1.4 (SA), T2.1 (AB), U1.2 (GND), U2.1 (ADJ/GND)
unnamed: D3.1 (K), T1.3 (AB), U1.1 (SW)
unnamed: D4.1 (A), T1.1 (SB)
unnamed: D7.1 (K), R20.1
unnamed: C6.2, T2.2 (AA)
unnamed: R1.1, R2.2, U1.4 (CHARGE)
unnamed: R4.2, U1.3 (nDONE)

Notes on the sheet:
IGN
80mA current limiting
300v may be substituted
trigger transformer
15-24VIN
Dummy pins for mechanical mounting
E-Field Igniter Design Adapted from Plasma Toroid design by Sky-guided
HV pulse capacitively ionizes Xe gas
fly-wire contact pressed against globe

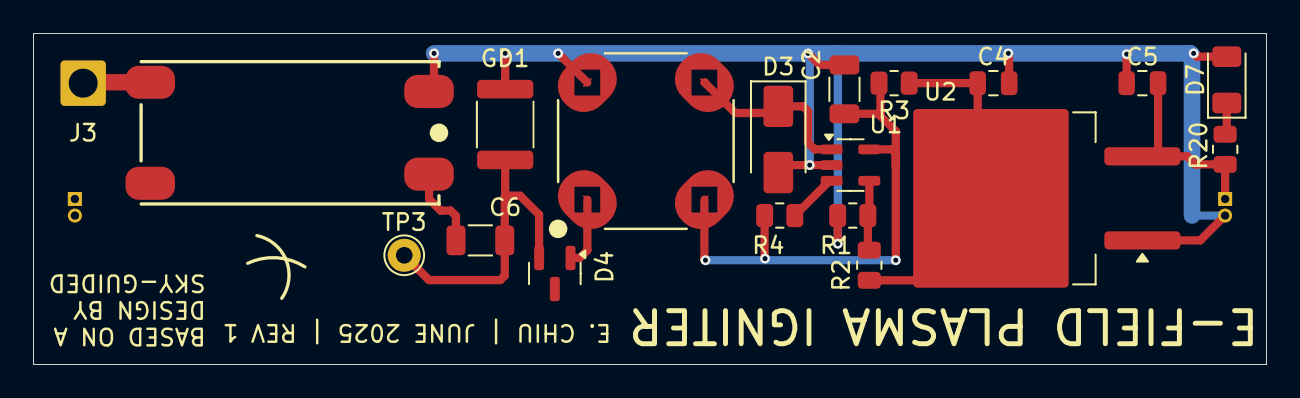
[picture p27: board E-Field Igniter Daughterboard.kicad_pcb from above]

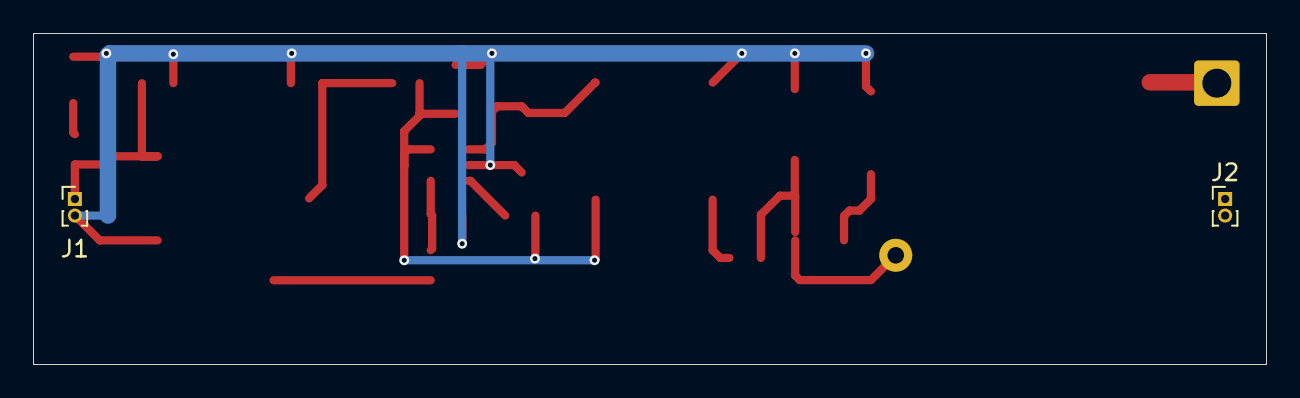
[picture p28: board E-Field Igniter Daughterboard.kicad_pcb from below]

Board: 2 copper layers, 74.5 x 20.0 mm, 21 parts (2 on the bottom side), 12 nets.

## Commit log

2025-04-30 placement complete, commit before routing
    [PlasmaTransformer.kicad_pcb, PlasmaTransformer.kicad_sch]
2025-04-30 layout complete, commit before resync
    [PlasmaTransformer.kicad_pcb, PlasmaTransformer.kicad_sch]
2025-04-30 final edits, silkscreens, generate Rev 1 manufacturing files
    [PlasmaTransformer-B_Cu.gbl, PlasmaTransformer-B_Mask.gbs, PlasmaTransformer-Edge_Cuts.gm1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]
2025-05-20 adding BOM files and 3D design for coil support and fan shroud for 130cm globe
    [122mm-CoilForm.ipt, 122mm-CoilForm.stl, FanShroud.ipt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]
2025-05-20 updated 122mm coil form design
    [122mm-CoilForm.ipt, 122mm-CoilForm.stl]
2025-05-20 added foot for airflow
    [FanShroud.ipt]
2025-05-27 Updated rev 2 design and manufacturing files. Note BOM is not up to date.
    [122mm-CoilForm.ipt, FanShroud-Foot.stl, FanShroud.ipt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]
2025-05-27 added design for 20cm globe
    [FanShroud-20cm.ipt, FanShroud-20cm.stl, FanShroud-Foot-20cm.stl]
2025-06-07 adding corrugated shroud design, BOM for dual fet driver
    [Corrugated-FanShroud-20cm.ipt, FanShroud-20cm.ipt, heatsink-dual-CNC.dxf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]
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2025-06-20 added coil form and new version of shroud with notch for fan wires
    [187mm-CoilForm.ipt, 187mm-CoilForm.stl, Corrugated-FanShroud-20cm.ipt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]
2025-06-23 modifying recommended values for successful 20cm toroid halo
    [122mm-CoilForm.ipt, 122mm-CoilForm.stl, 187mm-CoilForm.ipt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]
2025-06-23 added front shield to spacer to prevent people touching the coil, and recessed the coil down also to make it more difficult to accidentally touch the coil. Removed lower cooling holes as they don't r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
    [Corrugated-FanShroud-20cm-3mmSpacer.stl, Corrugated-FanShroud-20cm-Foot.stl, Corrugated-FanShroud-20cm.ipt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]
2025-06-23 reorganized stls into folders to make them easier to find
    [122mm-CoilForm.stl, 187mm-CoilForm.stl, Corrugated-FanShroud-13cm.stl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]
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2025-06-25 Update README.md
    added step to tighten mosfet screw
2025-06-27 rev 3 PCB adds auto ignite
    [4xDisplay.ipt, Corrugated-FanShroud-13cm.ipt, Corrugated-FanShroud-20cm.ipt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]
2025-06-28 Design cleanup, part selection and BOM update
    [PlasmaTransformer.kicad_pcb, PlasmaTransformer.kicad_sch]
2025-06-28 adding design and manufacturing files, not BOM is not yet complete
    [E-Field Igniter Daughterboard.kicad_pcb, E-Field Igniter Daughterboard.kicad_sch]
2025-06-28 part selection and bom
    [E-Field Igniter Daughterboard.kicad_pcb, E-Field Igniter Daughterboard.kicad_sch]
2025-06-28 graphical fixes to BOM
    [PlasmaTransformer.kicad_pcb, PlasmaTransformer.kicad_sch]
2025-07-01 added feet mounting holes to 13cm shroud
    [Corrugated-FanShroud-13cm.ipt, Corrugated-FanShroud-20cm.ipt]
2025-07-08 Updating to new design with snap-in front cover
    [122mm-CoilForm.stl, 187mm-CoilForm.stl, Corrugated-FanShroud-13cm.ipt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]
2025-07-08 adding 3d print files with new design with cover
    [122mm-CoilForm-4mmCoil.stl, 187mm-CoilForm-4mmCoil.stl, Corrugated-FanShroud-13cm-Cover.stl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]
2025-07-08 reorganizing PCB files into folders
    [4xDisplay.ipt, DisplayConcept.iam, E-Field Igniter Daughterboard.kicad_pcb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]
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2025-07-08 update links in assembly
    [DisplayConcept.iam]
2025-07-11 adding rev 3B with RF node igniter design
    [PlasmaTransformer-RF-Node-Igniter.kicad_pcb, PlasmaTransformer-RF-Node-Igniter.kicad_sch]
2025-07-11 fixced clearances and generated gerbers
    [PlasmaTransformer-RF-Node-Igniter.kicad_pcb]
2025-07-11 Update README.md
    fixed bowden tube lengths
2025-07-17 added a mount for a 42x24x16mm common mode ferrite to protect the power supply.
    [Corrugated-FanShroud-20cm-Cover.stl, Corrugated-FanShroud-20cm-MainShroud.stl, Corrugated-FanShroud-20cm.ipt]
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2025-07-29 layout updates for Rev 3B > Rev 4: gate selector caps, SMD footprint for trigger coil, silkscreen updates
    [15cmPasteMaskTemplate.ipt, Corrugated-FanShroud-13cm.ipt, DrokSupplyCase.ipt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]
2025-07-30 13cm V2 design WIP, updates to Rev 4 PCB
    [Corrugated-FanShroud-13cm-V2.ipt, Corrugated-FanShroud-13cm.ipt, PlasmaTransformer-RF-Node-Igniter.kicad_pcb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]
2025-07-31 create updated 13cm design with coil spacer and cover
    [Corrugated-FanShroud-13cm-Cover.stl, Corrugated-FanShroud-13cm-Foot.stl, Corrugated-FanShroud-13cm-MainShroud.stl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]
2025-07-31 Rolling auto igniter Rev 4 into the main folder
    [PlasmaTransformer-B_Cu.gbl, PlasmaTransformer-B_Mask.gbs, PlasmaTransformer-Edge_Cuts.gm1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]
2025-07-31 moving deprecated versions. RF tap auto igniter design rolled into main rev 4
    [E-Field Igniter Daughterboard.kicad_pcb, E-Field Igniter Daughterboard.kicad_sch, PlasmaTransformer-RF-Node-Igniter.kicad_pcb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]
2025-07-31 Rev 4 publish, silkscreen fixes, adding 3d models and footprint library.
    [15cmPasteMaskTemplate.ipt, 15cmPasteMaskTemplate.stl, DrokSupplyCase.ipt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]
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2025-10-10 improvements to ease of assembly, increased use of solid pours, layout complete, 1st DRC check complete.
    [PlasmaTransformer.kicad_pcb, PlasmaTransformer.kicad_sch]
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2025-10-12 Clean up, silkscreens, BOM cleanup, title blocks, fab notes, generate manufacturing files
    [PlasmaTransformer-B_Cu.gbl, PlasmaTransformer-B_Mask.gbs, PlasmaTransformer-Edge_Cuts.gm1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]
2025-10-12 updating 3D print files for 13cm globe rev 5
    [122mm-CoilForm-4mmCoil.stl, Corrugated-FanShroud-13cm-4coil-MainShroud.stl, Corrugated-FanShroud-13cm-4coil-Spacer.stl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]
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2025-10-30 adding missing 3d print files to 13cm set
    [80mm-CoilForm-for-pre-winding.stl, Corrugated-FanShroud-13cm-Cover.stl, Corrugated-FanShroud-13cm-Foot.stl]
2025-10-30 adding coil form for 6mm insulator 13cm Globe coil
    [122mm-CoilForm-6mmCoil.ipt]
2025-11-06 Update README.md
    Added Rev 5 assembly note about socket holes too big for press fit
2025-11-07 Update README.md corrected BOM reference
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2026-07-17 adding power supply case for "585W" power supply
    [PowerSupplyCase-585W-Base.stl, PowerSupplyCase-585W-Top.stl, PowerSupplyCase-585W.ipt]
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2026-07-27 adding new 3d models for power supplies and experimental donut
    [13cm-Spacer-10cmDonutEnvelope-5mm.stl, 13cm-Spacer-10cmDonutEnvelope.ipt, 13cm-Spacer-10cmDonutEnvelope.stl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]
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
